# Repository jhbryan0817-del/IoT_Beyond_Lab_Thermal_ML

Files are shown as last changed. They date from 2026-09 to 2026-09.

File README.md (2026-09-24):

# Edge Thermal Occupancy ML @ HKU

We introduce the privacy-oriented occupancy inference system using a telemetry of distributed 32 × 24 thermal nodes, which is used to train a model that accurately infers the availability of a specific area with unique context. Libraries at HKU, such as the Chi Wah Learning Commons, are unique in that there are no strictly defined seats. Availability is highly subjective due to many variables present. Therefore, the thermal matrix will be paired directly against the perceived availability score, which would be considered the ground truth. The goal is to create a system that is mature enough to provide useful qualitative information to students who are making decisions throughout their day.

## Target System Architecture

- Each node captures low-resolution thermal frames within a defined zone.
- The edge model maps thermal data directly to an availability estimate.
- The node transmits a packet consisting of the zone identifier, normalized availability estimate, confidence value, timestamp, and system metadata.
- LoRa provides node-to-server communication.
- The server consolidates zone-level estimates for downstream display interfaces and services.

## Repository Structure

- `Thermal_CAD/` — Rev B Fusion enclosure with a flat front, protruding thermal sensor, rear access for a 50 × 40 × 8 mm 2000 mAh battery, locating lid collars, and independent direct-thread M3 mounts. Includes three printable STL parts, STEP exports, previews and CAD/mesh checks. See [assembly notes](Thermal_CAD/Design-and-assembly-notes.md).

- `Hardware/` — HKU Thermal Node Rev 1.1 carrier: MLX90640 thermal sensor positioned away from module heat, corrected local power conditioning, an 80 × 40 mm enclosure-friendly outline, and I²C mapped to Heltec V3 GPIO41/GPIO42 instead of reserved pins. Includes KiCad sources, project-local libraries, BOMs, and the retained hardware licence.

## Lineage and Acknowledgements

Hardware Rev 1.1 is derived from the GPL-3.0 [CrowdAware node](https://github.com/crowdaware-inno-wing-iot/crowdaware-node). It keeps the original low-resolution thermal-node concept while improving thermal separation, decoupling, mechanics, source portability, and Heltec V3 pin compatibility. Attribution and a copy of the applicable licence are retained in `Hardware/`.

## About IoT Beyond Lab

Established in September 2026, the team is based in Innovation Wing at the University of Hong Kong. The mission is to build and **deploy** different IoT applications that will leave a lasting impact, hence inspiring the name "IoT Beyond Lab". Other than this thermal ML project, the team also partners with Chulalongkorn University (CSII) in Thailand to develop IoT-based solutions that mitigates flood-induced disaster impact.

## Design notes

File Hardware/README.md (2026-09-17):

# HKU Thermal Node Rev 1.1

Rev 1.1 is the current carrier-board design for a Heltec WiFi LoRa 32 V3 and MLX90640 low-resolution thermal occupancy node.

## Hardware definition

| Property | Specification |
|---|---|
| Board | 80 × 40 mm, two copper layers, four M3 mounting holes |
| Sensor | MLX90640ESF-BAA-000-TU, 32 × 24 pixels, 110° × 75° field of view |
| Controller/radio | Heltec WiFi LoRa 32 V3 with frequency-matched external antenna |
| Module connection | Two 1×18, 2.54 mm female socket strips |
| SDA | GPIO41, Heltec J3 pin 15, carrier J1 pad 7 |
| SCL | GPIO42, Heltec J3 pin 16, carrier J1 pad 5 |
| Sensor supply | Switchable 3.3 V `V_EXT`; GPIO36 active-low enable |
| Pull-ups | `R1`, `R2`: 1 kΩ to `V_EXT` |
| Decoupling | `C1`: 100 nF; `C2`: 10 µF |
| Factory-SMT scope | `C1`, `C2`, `R1`, `R2` |
| Manual scope | `A1`, two socket strips represented by `J1`, Heltec module, antenna, and mechanics |

## Rev 1.1 changes from CrowdAware

| Change | Reason |
|---|---|
| MLX90640 moved outside the Heltec footprint | Reduces heating influence from the controller, display, regulator, and radio while giving the sensor a clearer field region. |
| Board changed to an 80 × 40 mm rectangle with four M3 holes | Defines a regular mechanical and enclosure interface. |
| Sensor decoupling changed to 100 nF local plus 10 µF bulk capacitance | Improves the local sensor supply arrangement. |
| I²C pull-ups connected to `V_EXT` instead of always-on `3V3` | Keeps the bus high level in the sensor power domain and avoids back-powering when that rail is disabled. |
| SDA moved to GPIO41/J1 pad 7 and SCL moved to GPIO42/J1 pad 5 | Avoids reserved Heltec V3 GPIO34/GPIO33 and matches the intended firmware mapping. |
| `V_EXT` connection changed from a local copper island to an explicit trace | Makes the switched power path unambiguous. |
| Module sockets corrected from 1×20 to 1×18 | Matches the Heltec WiFi LoRa 32 V3 pin count and footprint. |
| MLX90640 and passive order codes corrected | Aligns the design with the specified sensor package and active component selections. |
| Project-local symbols and footprints added | Keeps the Rev 1.1 KiCad source portable and internally consistent. |
| Silkscreen identifies `Thermal Node Occupancy ML`, Rev 1.1, HKU Innovation Wing IoT Beyond Lab, and its CrowdAware basis | Tailors the carrier to the HKU deployment while preserving upstream credit on the board. |

Rev 1.1 is derived from the GPL-3.0 CrowdAware node. The full acknowledgement is in the repository-level `README.md`, and the retained licence is `COPYING-HARDWARE-GPL-3.0.txt`.

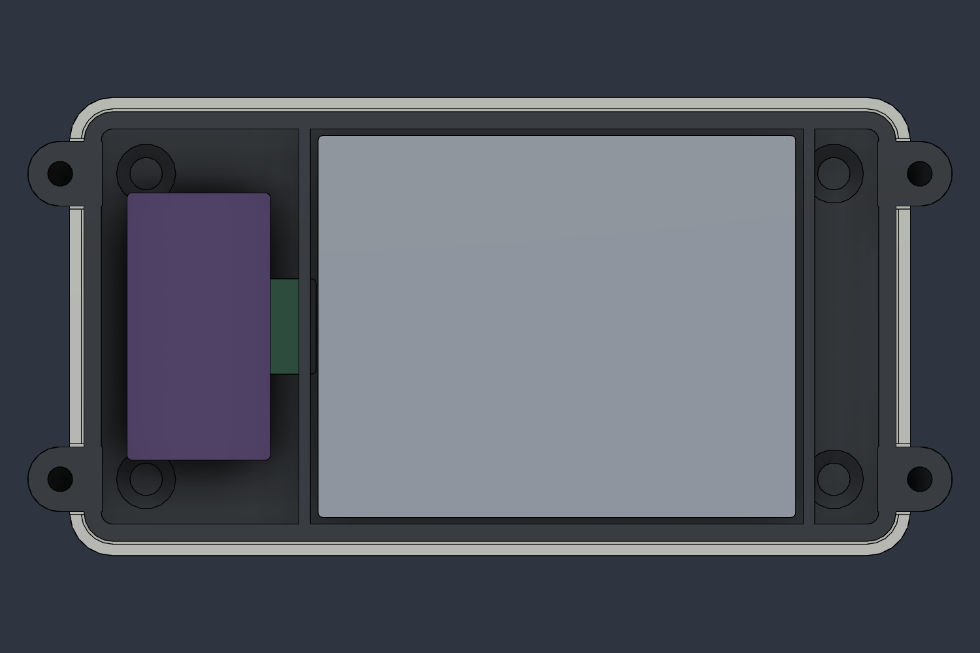
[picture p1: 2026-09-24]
Thermal_CAD/rear-open.png

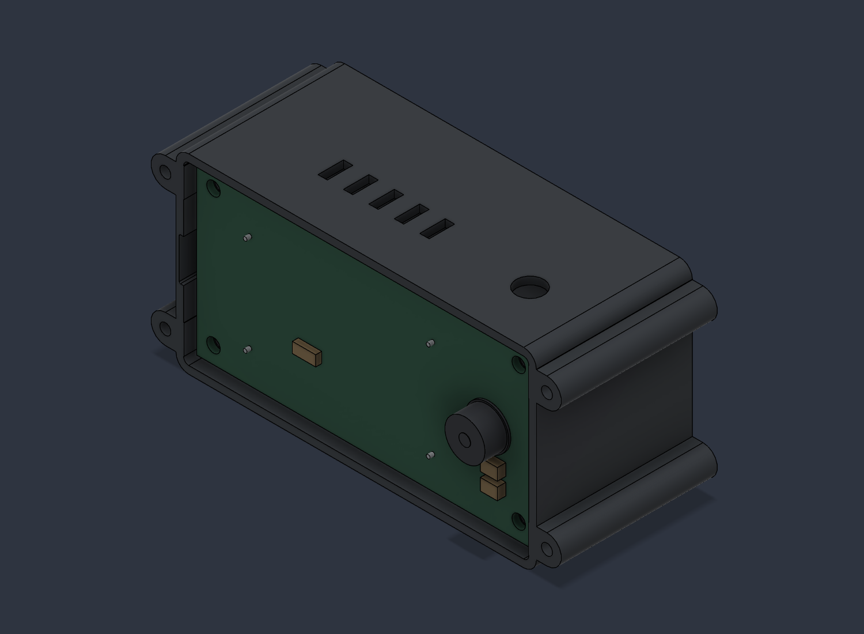
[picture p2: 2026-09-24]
Thermal_CAD/front-open.png

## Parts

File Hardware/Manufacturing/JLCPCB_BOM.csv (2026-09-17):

Comment | Designator | Footprint | LCSC Part #
100 nF 50 V X7R ±10% | C1 | 1206 | C24497
10 uF 50 V X5R ±10% | C2 | 1206 | C13585
1 kOhm ±1% | R1,R2 | 0603 | C21190

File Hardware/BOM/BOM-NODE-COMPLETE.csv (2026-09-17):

Reference | Qty per node | Category | Item | Manufacturer | Manufacturer Part Number | Mouser Number | Outsourced PCBA | Notes
PCB1 | 1 | Fabricated PCB | HKU Thermal Node Rev 1.1 carrier | Custom | Rev 1.1 |  | Bare-board fabrication | 80 x 40 mm carrier; four M3 mounting holes
C1 | 1 | Capacitor | 100 nF 50 V X7R 1206 10% | KEMET | C1206C104K5RAC | 80-C1206C104K5RAC | Yes - SMT | MLX90640 local decoupling
C2 | 1 | Capacitor | 10 uF 10 V X5R 1206 10% | KEMET | C1206C106K8PACTU | 80-C1206C106K8P | Yes - SMT | MLX90640 bulk decoupling
R1,R2 | 2 | Resistor | 1 kOhm 0603 5% | YAGEO | SR0603JR-7T1KL | 603-SR0603JR-7T1KL | Yes - SMT | SCL and SDA pull-ups to V_EXT
A1 | 1 | Thermal sensor | 32x24 array; 110x75 degree FOV; tube pack | Melexis | MLX90640ESF-BAA-000-TU | 482-MLX90640ESFBAATU | No - manual THT | Pin-1 orientation defined by PCB footprint
J1 | 2 | Socket strip | 1x18 straight female socket; 2.54 mm pitch | Samtec | SSW-118-01-G-S | 200-SSW11801GS | No - manual THT | KiCad designator J1 represents both strips
MOD1 | 1 | Controller/radio module | WiFi LoRa 32 V3 | Heltec Automation | Frequency variant to be confirmed |  | No - plug in | Absent from carrier-board BOM by design
ANT1 | 1 | Antenna | LoRa antenna and matching IPEX/u.FL lead if required | To be confirmed | Match MOD1 frequency variant |  | No - attach separately | Frequency matched to MOD1; provides the radio RF load
BAT1 | 1 | Battery | Protected 1S LiPo pouch; 3.7 V nominal; 2000 mAh; 7.4 Wh; 1C | MakerFocus or equivalent | 3450-1-2000-1S; SH1.25-2 plug |  | No - attach separately | Built-in PCM; at least 1 A discharge capability; verify connector polarity against MOD1 before connection; use a certified pack for deployment
ENC1 | 1 | Mechanical | Custom enclosure with unobstructed thermal aperture | Custom | To be designed |  | No | Sensor FOV requires an LWIR-transmissive aperture; ordinary plastic and glass are opaque to LWIR
H1-H4 | 4 | Mechanical | M3 standoffs and fasteners | To be confirmed | Length depends on enclosure |  | No | Standoff length defined by enclosure stack-up

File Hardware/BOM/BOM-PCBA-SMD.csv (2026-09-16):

Reference | Qty | Value | Manufacturer | Manufacturer Part Number | Mouser Number | Assembly Partition
C1 | 1 | 100 nF 50 V X7R 1206 10% | KEMET | C1206C104K5RAC | 80-C1206C104K5RAC | Factory SMT
C2 | 1 | 10 uF 10 V X5R 1206 10% | KEMET | C1206C106K8PACTU | 80-C1206C106K8P | Factory SMT
R1,R2 | 2 | 1 kOhm 0603 5% | YAGEO | SR0603JR-7T1KL | 603-SR0603JR-7T1KL | Factory SMT

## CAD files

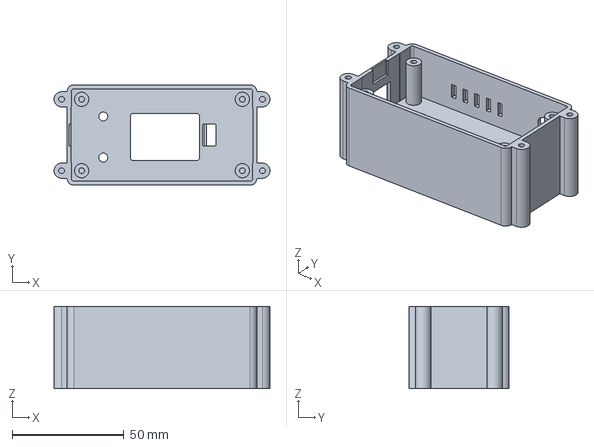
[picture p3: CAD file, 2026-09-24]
Thermal_CAD/main-housing.step
96.8 x 45.0 x 36.8 mm

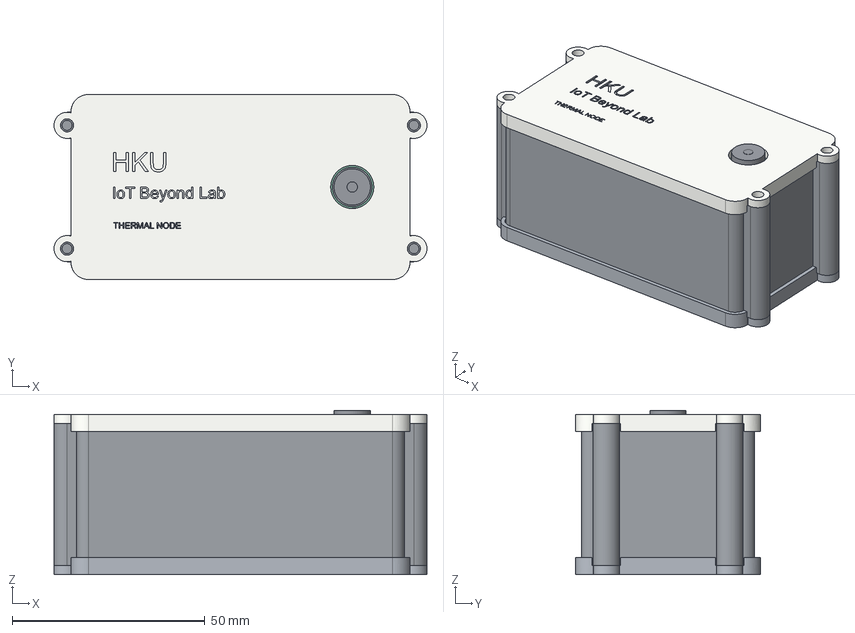
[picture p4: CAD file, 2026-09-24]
Thermal_CAD/HKU-thermal-enclosure-assembly.step
96.8 x 48.0 x 42.6 mm

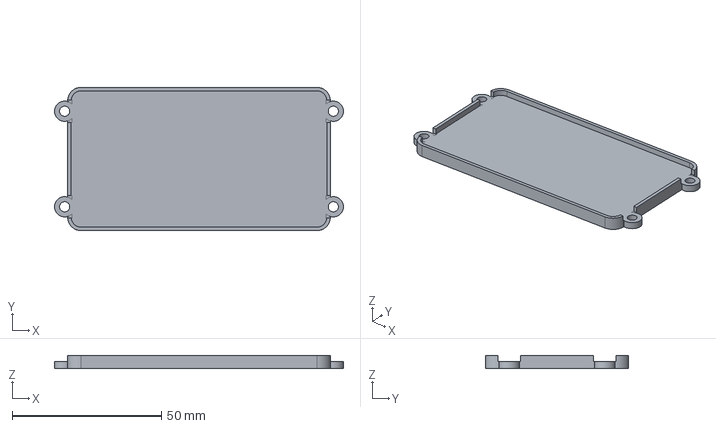
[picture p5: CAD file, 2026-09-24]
Thermal_CAD/rear-lid.step
96.8 x 48.0 x 4.40 mm

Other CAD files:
Thermal_CAD/front-lid.step
Thermal_CAD/HKU-thermal-enclosure.f3d
Thermal_CAD/front-lid.stl
Thermal_CAD/main-housing.stl
Thermal_CAD/rear-lid.stl

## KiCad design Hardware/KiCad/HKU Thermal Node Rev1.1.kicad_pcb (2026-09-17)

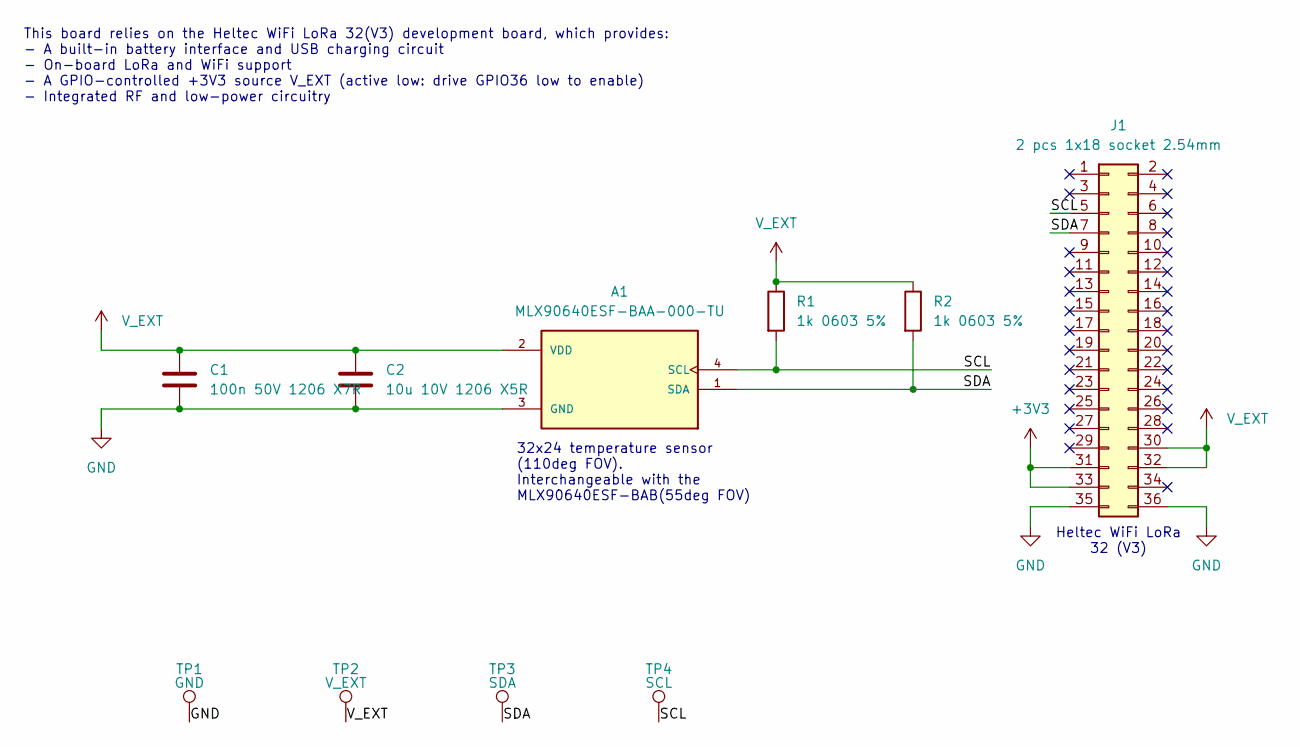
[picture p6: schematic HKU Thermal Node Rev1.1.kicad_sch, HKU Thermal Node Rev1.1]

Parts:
A1: MLX90640ESF-BAA-000-TU; PARTREV 11; Mouser No. 482-MLX90640ESFBAATU
C1: 100n 50V 1206 X7R; C_1206_3216Metric_Pad1.33x1.80mm_HandSolder; Mouser No. 80-C1206C104K5RAC
C2: 10u 10V 1206 X5R; C_1206_3216Metric_Pad1.33x1.80mm_HandSolder; Mouser No. 80-C1206C106K8P
J1: 2 pcs 1x18 socket 2.54mm; Connector_HeltecWiFiLoRa32v3; Mouser No. 200-SSW11801GS (order 2)
R1, R2: 1k 0603 5%; R_0603_1608Metric_Pad0.98x0.95mm_HandSolder; Mouser No. 603-SR0603JR-7T1KL
TP1: GND; TestPoint_Plated_Hole_D2.0mm
TP2: V_EXT; TestPoint_Plated_Hole_D2.0mm
TP3: SDA; TestPoint_Plated_Hole_D2.0mm
TP4: SCL; TestPoint_Plated_Hole_D2.0mm

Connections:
+3V3: J1.31, J1.33
/SCL: A1.4 (SCL), J1.5, R1.2, TP4.1
/SDA: A1.1 (SDA), J1.7, R2.2, TP3.1
GND: A1.3 (GND), C1.2, C2.2, J1.35, J1.36, TP1.1
V_EXT: A1.2 (VDD), C1.1, C2.1, J1.30, J1.32, R1.1, R2.1, TP2.1

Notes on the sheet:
This board relies on the Heltec WiFi LoRa 32(V3) development board, which provides: - A built-in battery interface and USB charging circuit - On-board LoRa and WiFi support - A GPIO-controlled +3V3 source V_EXT (active low: drive GPIO36 low to enable) - Integrated RF and low-power circuitry
Heltec WiFi LoRa 32 (V3)
32x24 temperature sensor (110deg FOV). Interchangeable with the MLX90640ESF-BAB(55deg FOV)

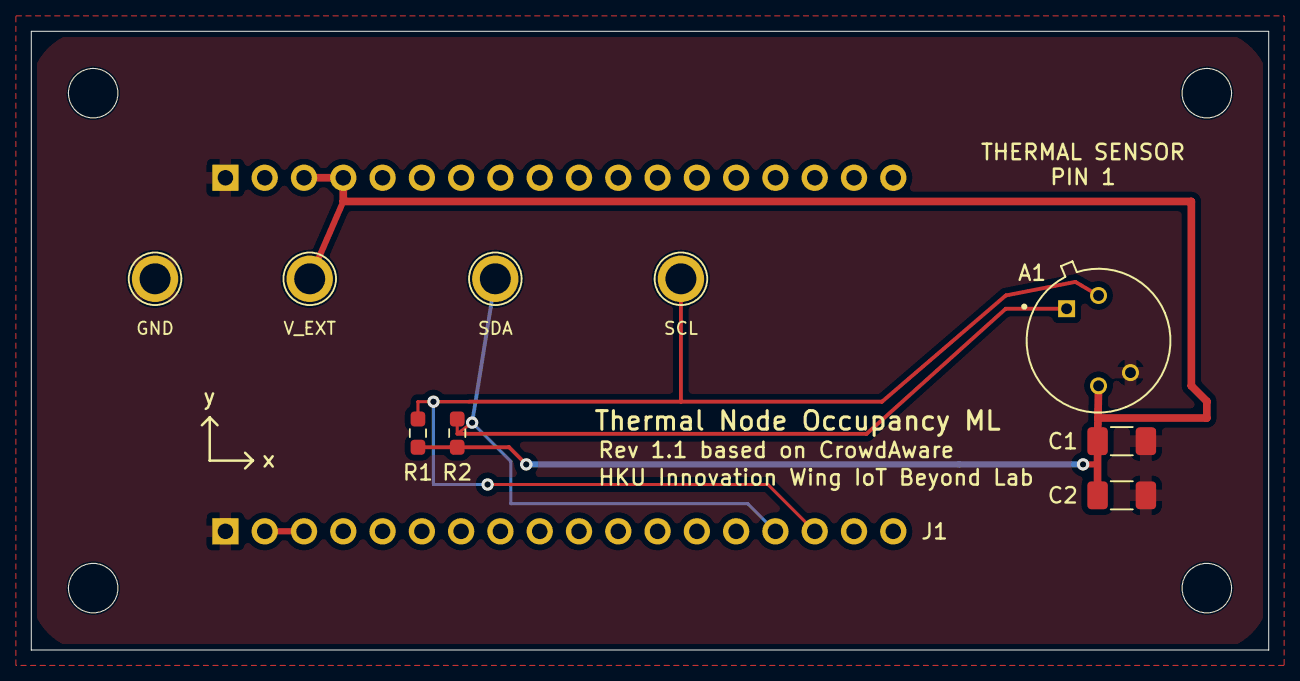
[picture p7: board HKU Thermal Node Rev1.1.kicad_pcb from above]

Board: 2 copper layers, 80.0 x 40.0 mm, 14 parts (1 on the bottom side), 5 nets.

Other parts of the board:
H1, H2, H3, H4: MountingHole_3.2mm_M3

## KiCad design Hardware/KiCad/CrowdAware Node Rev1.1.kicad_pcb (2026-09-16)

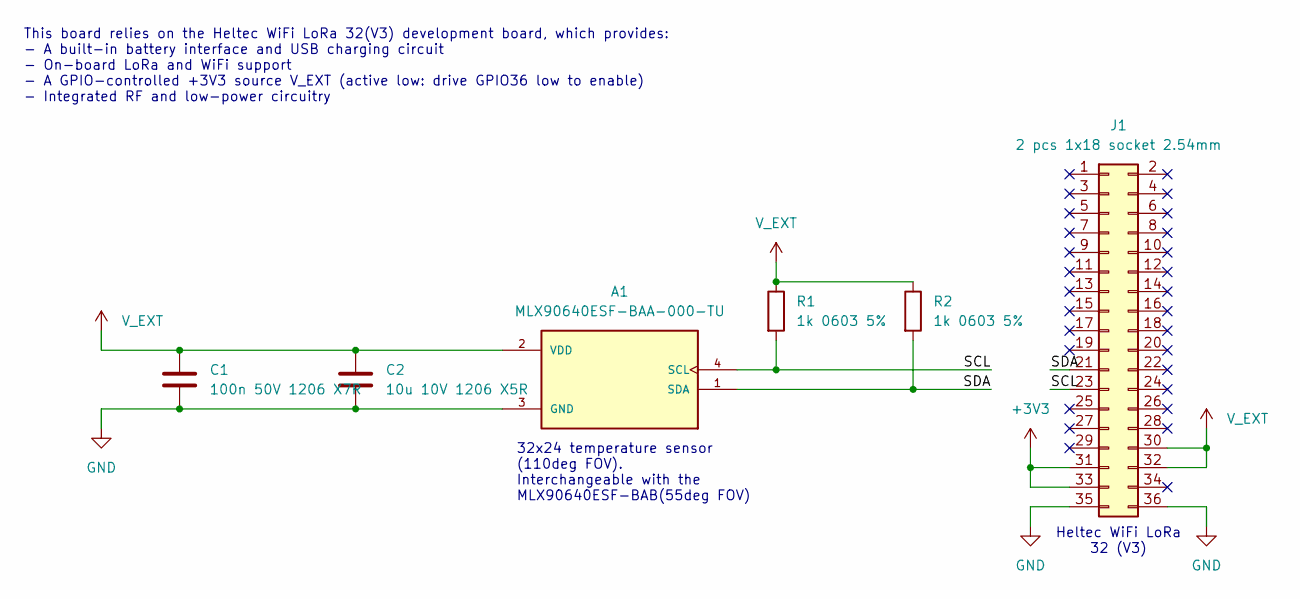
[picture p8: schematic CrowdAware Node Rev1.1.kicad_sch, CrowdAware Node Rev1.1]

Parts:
A1: MLX90640ESF-BAA-000-TU; PARTREV 11; Mouser No. 482-MLX90640ESFBAATU
C1: 100n 50V 1206 X7R; C_1206_3216Metric_Pad1.33x1.80mm_HandSolder; Mouser No. 80-C1206C104K5RAC
C2: 10u 10V 1206 X5R; C_1206_3216Metric_Pad1.33x1.80mm_HandSolder; Mouser No. 80-C1206C106K8P
J1: 2 pcs 1x18 socket 2.54mm; Connector_HeltecWiFiLoRa32v3; Mouser No. 200-SSW11801GS (order 2)
R1, R2: 1k 0603 5%; R_0603_1608Metric_Pad0.98x0.95mm_HandSolder; Mouser No. 603-SR0603JR-7T1KL

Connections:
+3V3: J1.31, J1.33
/SCL: A1.4 (SCL), J1.23, R1.2
/SDA: A1.1 (SDA), J1.21, R2.2
GND: A1.3 (GND), C1.2, C2.2, J1.35, J1.36
V_EXT: A1.2 (VDD), C1.1, C2.1, J1.30, J1.32, R1.1, R2.1

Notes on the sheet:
This board relies on the Heltec WiFi LoRa 32(V3) development board, which provides: - A built-in battery interface and USB charging circuit - On-board LoRa and WiFi support - A GPIO-controlled +3V3 source V_EXT (active low: drive GPIO36 low to enable) - Integrated RF and low-power circuitry
Heltec WiFi LoRa 32 (V3)
32x24 temperature sensor (110deg FOV). Interchangeable with the MLX90640ESF-BAB(55deg FOV)

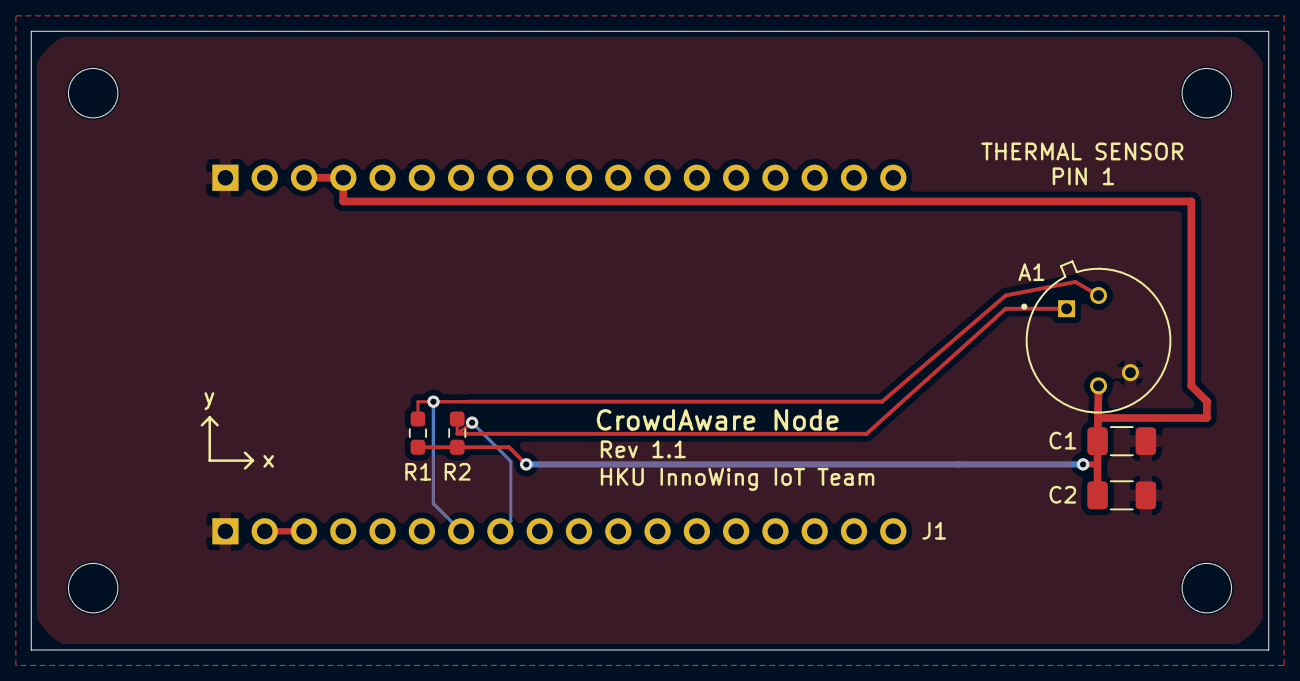
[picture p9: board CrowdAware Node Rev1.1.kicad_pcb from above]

Board: 2 copper layers, 80.0 x 40.0 mm, 10 parts (1 on the bottom side), 5 nets.

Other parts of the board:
H1, H2, H3, H4: MountingHole_3.2mm_M3

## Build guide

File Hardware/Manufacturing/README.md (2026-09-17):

# JLCPCB production package — HKU Thermal Node Rev 1.1

Upload `HKU_Thermal_Node_Rev1.1_Gerbers.zip` as the PCB file, then upload `JLCPCB_BOM.csv` and `JLCPCB_CPL.csv` for assembly.

## Order settings

| Setting | Value |
|---|---|
| Quantity | 10 boards / 10 assembled boards |
| PCB | 2-layer FR-4, 80 × 40 mm, 1.6 mm, 1 oz copper |
| Finish | Lead-free HASL |
| Solder mask / silkscreen | Green / white |
| Stack-up | JLCPCB default 2-layer stack-up |
| Via covering | Tented |
| Panelization | Individual boards; no customer panel |
| Controlled impedance | No |
| Assembly | Economic PCBA, top side only |
| Factory-fitted references | C1, C2, R1, R2 only |

Do not factory-fit A1, J1, the Heltec module, antenna, battery, or mechanical parts. Fit these manually after delivery.

Use a Heltec WiFi LoRa 32 V3.2, 902–928 MHz variant, with a matching 920–925 MHz antenna. The module plugs into two 1×18, 2.54 mm female socket strips. Fit A1 as `MLX90640ESF-BAA-000-TU` and observe its pin-1 mark.

Before payment, confirm JLCPCB's previews show one 80 × 40 mm board and four top-side placements per board. C1, C2, R1, and R2 are non-polarized.

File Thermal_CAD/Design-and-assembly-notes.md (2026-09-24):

# Thermal enclosure — Rev B

Revised in the existing `Thermal_Enclosure` Autodesk Fusion design on 24 September 2026. This revision supersedes the original sloped front and 500 mAh battery arrangement.

## Changes

- Flat 2.4 mm front plate with the original engraved labels. An 11.2 mm opening exposes the thermal camera; the nominal optical face projects 1.03 mm above the plate.
- Separate removable rear battery lid, with four M3 screws. The front lid also has four M3 screws, independent of the PCB.
- Four PCB mounts at the existing 72 × 32 mm hole pattern, with blind 2.6 mm pilot holes for M3 screws to form threads directly in plastic. No nuts or inserts.
- Removed the four original battery shelves that blocked top insertion of the PCB.
- Both lids have 2 mm deep external locating collars, with 0.30 mm nominal clearance per side. They register the lids before screws are installed; they are not snap fits or interference fits.
- Rear pocket for the specified 3.7 V 2000 mAh 804050 battery, nominally 50 × 40 × 8 mm. The pocket is 51.6 × 41.4 mm, leaving 0.8 mm at each end and 0.7 mm at each side with the reference battery centered.
- Battery reference sits 0.2 mm above the rear lid for a thin insulating retention layer, with 3.6 mm clearance above the nominal pouch to the existing service floor. The pack lifts out through the back.
- A 6 × 10 mm passage through the existing floor connects the rear battery bay to the controller compartment. Route leads away from the screw tips and leave a service loop for opening the lid.
- A 15 × 28 × 8 mm antenna envelope is reserved beside the battery, accessible from the rear. This is an allocation, not a model of a specific SX1262-compatible antenna. Confirm antenna size and frequency before glue mounting. The existing SMA port is retained.

## Preserved geometry and necessary envelope changes

The carrier PCB, thermal camera, Heltec, 8.51 mm female sockets, assumed 2.54 mm male spacers, USB corridor, side vents, SMA port, and original OLED/button service openings retain their original positions. The larger rear battery covers the OLED access: open the rear lid and lift the battery to access it, as agreed.

The main wall footprint remains 85 × 45 mm. External screw bosses keep lid fasteners outside the PCB insertion path; the maximum width becomes 96.8 mm. Lid collars make the maximum depth 48 mm. Overall enclosure height is 41.6 mm, excluding the protruding camera and screw heads. The original internal coordinate system is retained, so some exported Z coordinates are negative.

## Files

- `HKU-thermal-enclosure.f3d`: editable Fusion design with the original timeline and revision features.
- `HKU-thermal-enclosure-assembly.step`: complete assembly with simplified hardware references.
- `main-housing.stl`, `front-lid.stl`, `rear-lid.stl`: the three printable parts, in millimetres. Corresponding STEP files are also supplied.
- `Revise-enclosure-in-Fusion.py`: revision script for the original Rev A design; run once, not on Rev B.
- `verification.json`, `mesh-verification.json`: CAD and mesh checks.

Do not print hardware reference bodies. The old battery tray and original shells are superseded.

## Fasteners and assembly

Use twelve M3 screws: four **M3 × 8 mm** for the PCB and four **M3 × 10 mm** for each lid. Lengths exclude the heads; use pan/button/socket heads, not countersunk heads. Lid holes are 3.4 mm clearance. Lid pilots are 8.5 mm deep; the 10 mm screws engage about 7.6 mm. PCB screws engage about 6.4 mm below the 1.6 mm board.

1. Print and deburr the three parts. Test each collar and the direct-thread pilots before fitting electronics. Pilot fit depends on printer and material; the CAD uses 2.6 mm, not modeled machine threads.
2. Insert the assembled PCB/Heltec stack from the front and seat it on the four posts. Install its four M3 × 8 mm screws with light torque.
3. Attach the antenna and route its coax and battery leads through the available corridor. Glue should not obstruct the lid or battery extraction.
4. Fit the front lid over the sensor and secure its four M3 × 10 mm screws.
5. Position the battery in the rear pocket with removable insulating retention material. Avoid squeezing the pouch. Close the rear lid and install its four M3 × 10 mm screws.

Print both lids with the flat outer face on the bed, collars upward. For the main housing, place the rear rim on the bed and inspect slicer support requirements for the existing internal service floor and side openings. PETG and a 0.4 mm nozzle are the original design assumptions. Do a first-article fit check before printing a batch.

## Verification limits

Fusion reports one solid per printable part, no unhealthy timeline features, and no volume intersections between the revised enclosure parts and the modeled hardware. The front PCB stack and rear battery extraction were checked at 0.5 mm increments over 50 mm with the lids removed; no housing collisions were found. All three STL meshes have closed two-face edges, consistent winding and positive volume. These are digital checks, not a physical fit certification.

CAD checks concern the supplied simplified component envelopes, not a physical assembly. Actual header stack, battery protection board/taped leads, antenna dimensions, connector access, thermal performance and RF performance still need a real fit check. The enclosure remains vented, with an open thermal aperture. See the retained Rev A build script and hardware documentation for original source dimensions and attribution.

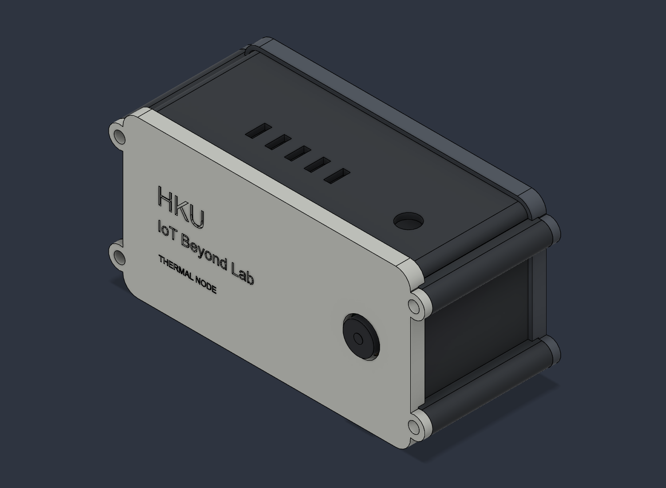
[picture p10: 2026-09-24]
Thermal_CAD/assembled-clean.png

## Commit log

2026-09-15 Add PCBA and complete-node bills of materials
    [BOM-NODE-COMPLETE.csv, BOM-PCBA-SMD.csv]
2026-09-15 Add CrowdAware Node Rev 1.1 KiCad sources
    [CrowdAware Node Rev1.1.kicad_pcb, CrowdAware Node Rev1.1.kicad_sch]
2026-09-16 Use declarative PCBA assembly classifications
    [BOM-PCBA-SMD.csv]
2026-09-16 Remove procedural notes from complete-node BOM
    [BOM-NODE-COMPLETE.csv]
2026-09-16 Finalize verified CrowdAware Node Rev 1.1 hardware
    [CrowdAware Node Rev1.1.kicad_pcb, CrowdAware Node Rev1.1.kicad_sch]
2026-09-16 Fix Rev 1.1 production blockers and rename hardware
    [BOM-NODE-COMPLETE.csv, HKU Thermal Node Rev1.1.kicad_pcb, HKU Thermal Node Rev1.1.kicad_sch]
2026-09-17 Update Rev 1.1 PCB branding
    [HKU Thermal Node Rev1.1.kicad_pcb]
2026-09-17 Add Rev 1.1 hardware test points
    [BOM-NODE-COMPLETE.csv, HKU Thermal Node Rev1.1.kicad_pcb, HKU Thermal Node Rev1.1.kicad_sch]
2026-09-17 Update HKU Thermal Node Rev1.1.kicad_pcb
    [HKU Thermal Node Rev1.1.kicad_pcb]
2026-09-17 Add JLCPCB manufacturing package
    Gerbers and drills, SMD-only BOM/CPL, and concise order settings for 10 prototype boards.
    [JLCPCB_BOM.csv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]
2026-09-17 Add unzipped Gerber reference folder
    Adds the 11 individual fabrication and drill files corresponding exactly to the validated JLCPCB Gerber ZIP.
    [HKU Thermal Node Rev1.1-B_Cu.gbl, HKU Thermal Node Rev1.1-B_Mask.gbs, HKU Thermal Node Rev1.1-B_Paste.gbp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]
2026-09-24 Revise thermal enclosure with flat front and rear 804050 battery access
    [HKU-thermal-enclosure-assembly.step, HKU-thermal-enclosure.f3d, battery-tray.step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]
2026-09-25 Close SMA port and enlarge battery clearance in housing and rear lid
    [main-housing.stl, rear-lid.stl]
2026-09-25 Reinforce PCB screw posts with corner wall ribs
    [main-housing.stl]
2026-10-29 Add revised thermal enclosure STL with corrected USB clearance
    Export the edited Fusion housing with updated battery supports and access openings. STL coordinates are in millimeters; mesh has 7,532 triangles and closed manifold edges.
